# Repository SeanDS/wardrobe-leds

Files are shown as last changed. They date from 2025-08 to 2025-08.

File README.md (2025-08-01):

# Wardrobe light sensor/driver
This circuit allows for four independent light sensors and LED drivers. It can
be used to sense if a wardrobe (or any door) is opened and trigger an LED strip
to come on. It allows sensitivity of the LDR to be tuned using trimmers.

## Credits
Sean Leavey  
https://github.com/SeanDS

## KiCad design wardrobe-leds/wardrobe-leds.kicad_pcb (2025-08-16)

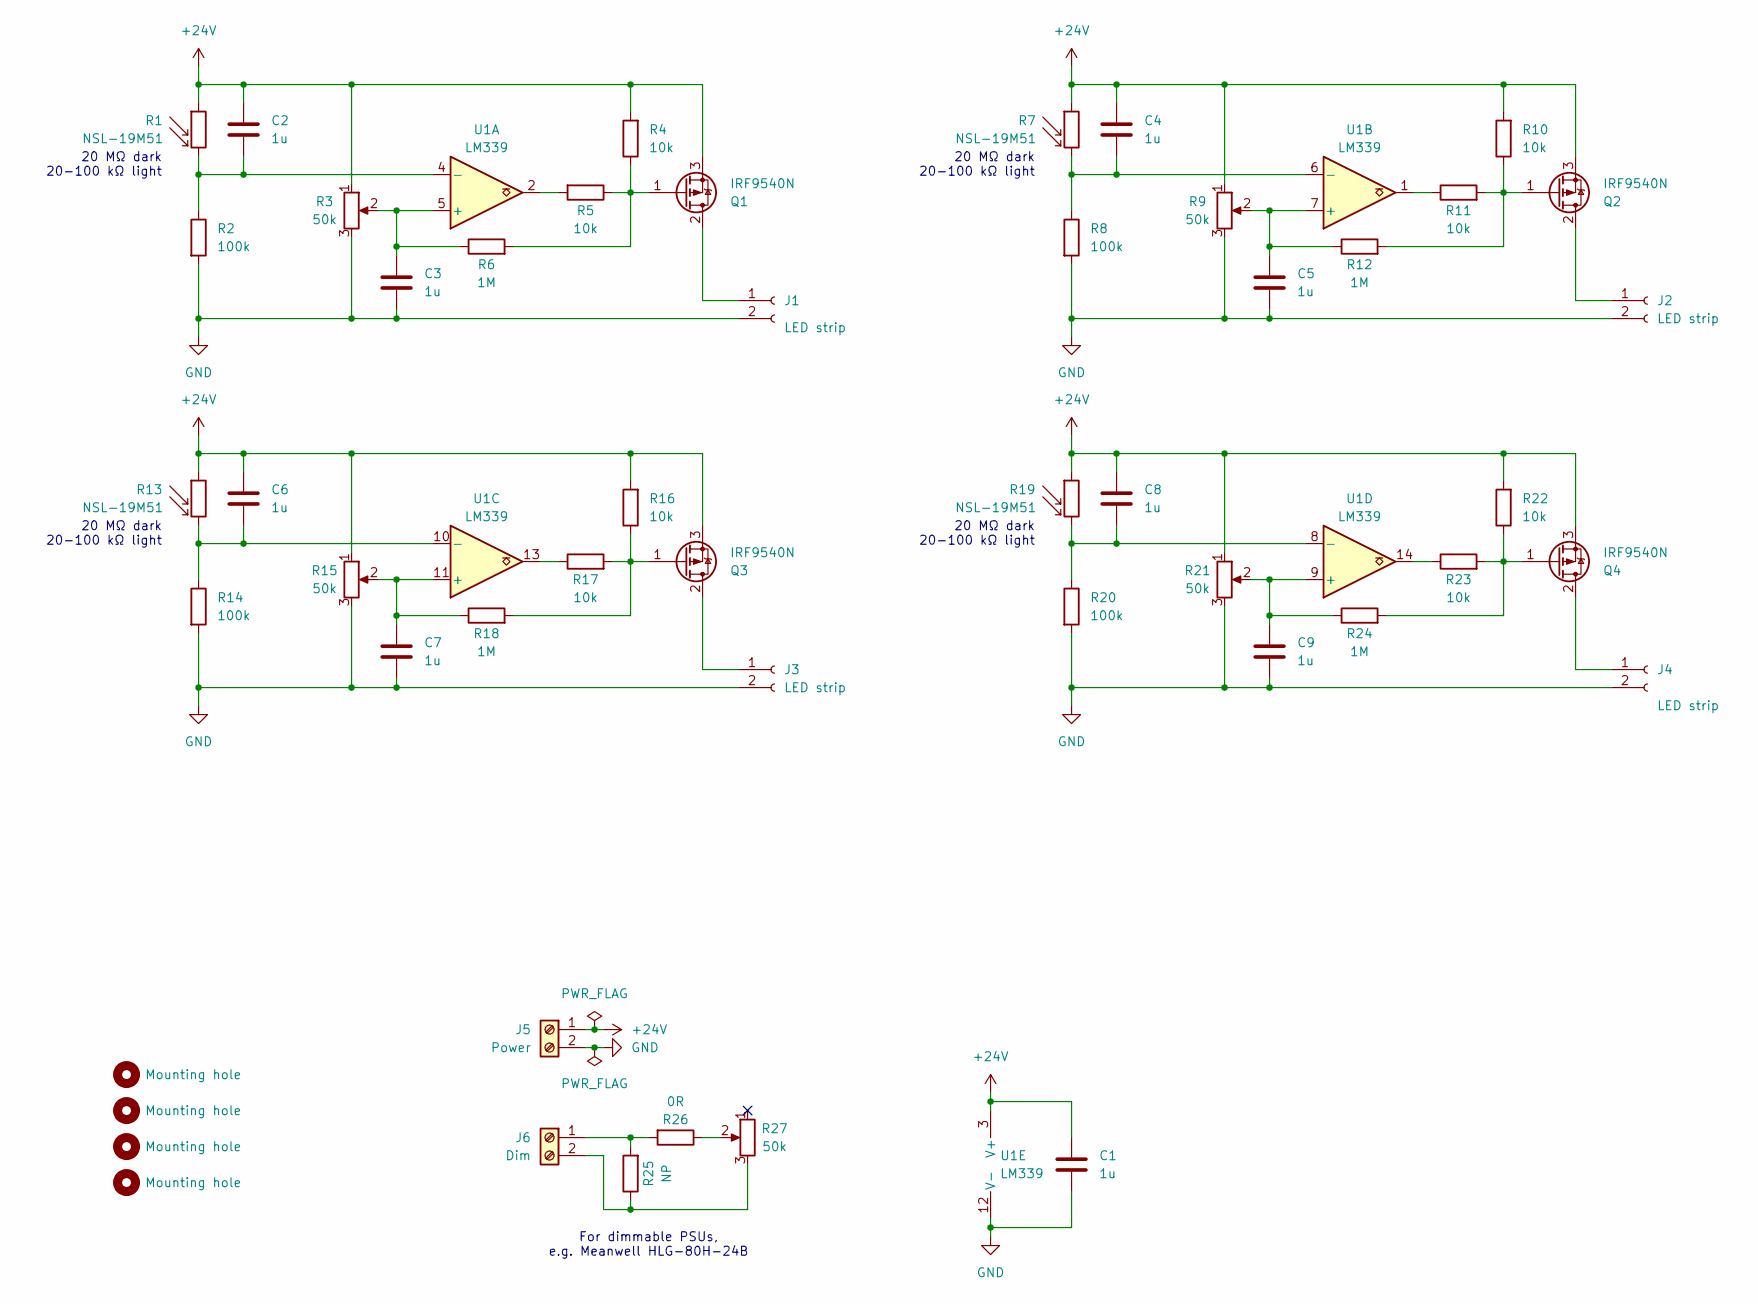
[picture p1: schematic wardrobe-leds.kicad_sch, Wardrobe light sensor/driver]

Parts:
C1, C2, C3, C4, C5, C6, C7, C8, C9: 1u; C_0805_2012Metric
H1, H2, H3, H4: Mounting hole; MountingHole_3.2mm_M3
J1, J2, J3, J4: LED strip; Molex_Nano-Fit_105313-xx02_1x02_P2.50mm_Horizontal
J5: Power; TerminalBlock_Phoenix_MKDS-3-2-5.08_1x02_P5.08mm_Horizontal
J6: Dim; TerminalBlock_Phoenix_MKDS-3-2-5.08_1x02_P5.08mm_Horizontal
Q1, Q2, Q3, Q4: IRF9540N; TO-220-3_Horizontal_TabDown
R1, R7, R13, R19: NSL-19M51; Molex_Nano-Fit_105313-xx02_1x02_P2.50mm_Horizontal
R2, R8, R14, R20: 100k; R_0805_2012Metric
R3, R9, R15, R21, R27: 50k; Potentiometer_Bourns_3314J_Vertical; MPN1 3314G-2-503E
R4, R5, R10, R11, R16, R17, R22, R23: 10k; R_0805_2012Metric
R6, R12, R18, R24: 1M; R_0805_2012Metric
R25: NP; R_0805_2012Metric
R26: 0R; R_0805_2012Metric
U1: LM339; SOIC-14_3.9x8.7mm_P1.27mm; MPN1 LM339D

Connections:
+24V: C1.1, C2.1, C4.1, C6.1, C8.1, J5.1, Q1.3 (S), Q2.3 (S), Q3.3 (S), Q4.3 (S), R1.1, R3.1, R4.2, R7.1, R9.1, R10.2, R13.1, R15.1, R16.2, R19.1, R21.1, R22.2, U1.3 (V+)
GND: C1.2, C3.2, C5.2, C7.2, C9.2, J1.2, J2.2, J3.2, J4.2, J5.2, R2.2, R3.3, R8.2, R9.3, R14.2, R15.3, R20.2, R21.3, U1.12 (V-)
unnamed: J1.1, Q1.2 (D)
unnamed: J2.1, Q2.2 (D)
unnamed: J3.1, Q3.2 (D)
unnamed: J4.1, Q4.2 (D)
unnamed: J6.1, R25.2, R26.2
unnamed: J6.2, R25.1, R27.3
unnamed: Q1.1 (G), R4.1, R5.1, R6.2
unnamed: Q2.1 (G), R10.1, R11.2, R12.2
unnamed: Q3.1 (G), R16.1, R17.2, R18.2
unnamed: Q4.1 (G), R22.1, R23.2, R24.2
unnamed: R5.2, U1.2
unnamed: R11.1, U1.1
unnamed: R17.1, U1.13
unnamed: R23.1, U1.14
unnamed: R26.1, R27.2
unnamed: C3.1, R3.2, R6.1, U1.5 (+)
unnamed: C2.2, R1.2, R2.1, U1.4 (-)
unnamed: C5.1, R9.2, R12.1, U1.7 (+)
unnamed: C4.2, R7.2, R8.1, U1.6 (-)
unnamed: C7.1, R15.2, R18.1, U1.11 (+)
unnamed: C6.2, R13.2, R14.1, U1.10 (-)
unnamed: C9.1, R21.2, R24.1, U1.9 (+)
unnamed: C8.2, R19.2, R20.1, U1.8 (-)

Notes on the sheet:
20 MΩ dark 20-100 kΩ light
For dimmable PSUs, e.g. Meanwell HLG-80H-24B

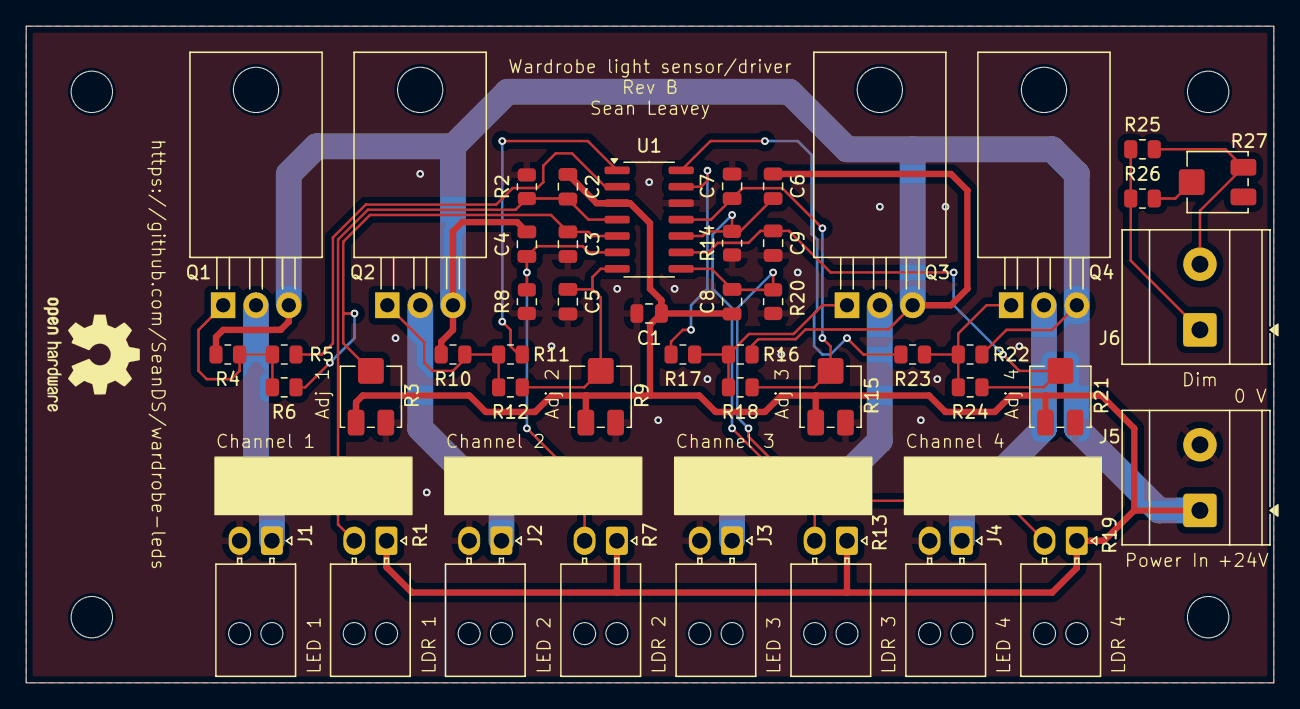
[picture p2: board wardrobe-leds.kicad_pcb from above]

Board: 2 copper layers, 96.5 x 50.8 mm, 51 parts (0 on the bottom side), 25 nets.

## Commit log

2025-08-01 Add first design
    [wardrobe-leds.kicad_pcb, wardrobe-leds.kicad_sch]
2025-08-16 Update driver to use P-channel MOSFET to avoid Vgs voltage drop; add dimmer control; add hysteresis
    [wardrobe-leds.kicad_pcb, wardrobe-leds.kicad_sch]
